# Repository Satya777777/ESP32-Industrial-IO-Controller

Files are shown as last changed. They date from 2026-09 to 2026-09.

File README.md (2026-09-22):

# ESP32 Industrial I/O Controller

A custom 4-layer ESP32-based industrial I/O controller designed in KiCad.

## Features

- ESP32-WROOM-32E
- 24 V input
- 0–10 V analog input
- 4–20 mA analog input
- RS485 communication
- USB-C programming/debugging
- 24 V relay output
- 5 V buck converter
- 3.3 V regulation
- 4-layer PCB
- Dedicated GND plane

## System Architecture

Architecture

## PCB

3D PCB

## Documentation

- [Datasheet & User Manual](docs/ESP32_Industrial_IO_Controller_Datasheet_User_Manual.pdf)
- [Design Process & Engineering Record](docs/ESP32_Industrial_IO_Controller_Design_Process.pdf)

## Hardware

- KiCad schematic
- KiCad PCB
- Gerber files
- Drill files

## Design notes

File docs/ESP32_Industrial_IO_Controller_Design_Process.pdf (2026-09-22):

ESP32 Industrial I/O Controller — Design Process
ENGINEERING DOCUMENT

# ESP32 Industrial I/O Controller

# Complete PCB Design Process & Engineering Record

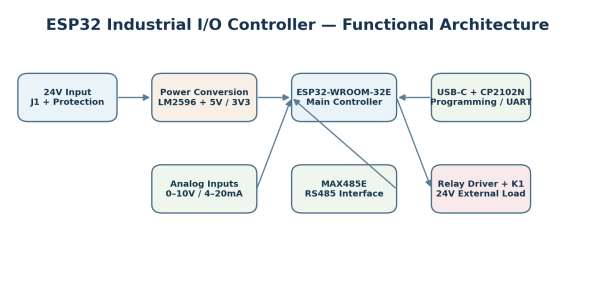
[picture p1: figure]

Document ID | EIC-4L-ENG-001
Documentation Revision | 1.0
Design Revision | Rev A — Routed PCB
Toolchain | KiCad PCB + Schematic Editors
Board | 4-layer FR-4, nominal 1.6 mm
Prepared for | Portfolio / GitHub / LinkedIn engineering record

Documentation note: This document records the design decisions and implementation state captured during the KiCad PCB development workflow. Values or performance limits not explicitly established in the project record are marked as design targets or items to verify before production.

# Contents

1. Project Definition
2. Requirements
3. Architecture and Partitioning
4. Component Selection
5. PCB Stackup and Design Rules
6. Schematic Development
7. Footprint and Mechanical Decisions
8. PCB Placement Evolution
9. Routing Strategy and Execution
10. Verification and DRC
11. Final Gerber Inspection
12. Key Design Decisions and Change Log
13. Final Engineering Status
14. Portfolio Documentation Notes

# 1. Project Definition

Goal. Design a compact industrial-style ESP32 controller PCB that combines 24V field power, protected 5V/3.3V rails, USB service access, RS485, analog process inputs, and a relay-controlled external load interface in one 4-layer board.

- Controller core: ESP32-WROOM-32E.
- Service interface: USB-C with CP2102N USB-UART bridge.
- Industrial communications: MAX485E RS485 transceiver.
- Analog interfaces: one 0–10V input and one 4–20mA input.
- Field power: nominal 24V input with protection and fused board power.
- Outputs: 24V relay interface; external load target up to 5A inductive through relay contacts.
- PCB approach: 4 layers, solid inner GND plane, edge-accessible field connectors.

# 2. Requirements

Category | Requirement / target | Implementation
Power | 24V field input | J1 → F1 → Q3 protection → 24V_PROTECTED
Power | 5V rail | LM2596S-5 buck stage
Power | 3.3V rail | TLV76733 linear regulator
USB | USB service/programming | USB-C + CP2102N
Analog | 0–10V sensor | Protected divider/filter to GPIO34
Analog | 4–20mA sensor | 150 Ω shunt + filter/protection to GPIO35
Comms | RS485 | MAX485E + A/B terminal
Output | Relay output | JQC-3FF-024-1Z SPDT relay
Load | External motor/load target | Up to 5A inductive at the external relay-contact path; verify final thermal/current margin before production
PCB | 4-layer, 1.6 mm nominal | F.Cu / In1.Cu / In2.Cu / B.Cu

# 3. Architecture and Partitioning

Figure 1. Functional architecture used to partition the PCB into power, digital, analog, communications, and relay zones.

- Power section kept in the lower portion of the board to isolate switching currents from analog and RF-sensitive circuitry.
- ESP32 placed near the upper center with its antenna facing the board edge and a dedicated keep-out region.
- Analog connectors placed at the left edge, with conditioning components immediately inboard.
- RS485 connector and MAX485E placed together at the right edge.
- Relay and external-load connector placed together in the lower-right zone.
- USB-C and CP2102N grouped at the upper-left service area.

# 4. Component Selection

Core components and selected packages. The selection was made around the required electrical function, field accessibility, and KiCad footprint/3D-model availability.

Function | Part / value | PCB package / footprint decision
MCU | ESP32-WROOM-32E | RF_Module:ESP32-WROOM-32D style WROOM footprint used in the project
USB-UART | CP2102N | QFN-24 footprint with exposed GND pad
RS485 | MAX485E | SOIC-8 footprint
5V buck | LM2596S-5 | Power IC with external diode / inductor / capacitors
3.3V LDO | TLV76733DRVx | SOT-23-6 family footprint used for the project symbol/PCB mapping
Relay | JQC-3FF-024-1Z | Relay_THT:Relay_SPDT_Hongfa_JQC-3FF_0XX-1Z
24V field terminals | Phoenix Contact MKDS family | 2-position 5.08 mm Phoenix footprint
3-way relay terminal | Phoenix Contact MKDS family | 3-position 5.08 mm Phoenix footprint

Function | Part / value | PCB package / footprint decision
Resistors | 10k, 20k, 47.5k, 150 Ω etc. | 0805 metric for SMD resistors
Caps | 0.1 µF to 22 µF SMD | 0603/0805/1206 selected by value/function
Bulk caps | 680 µF / 220 µF | Through-hole radial footprints

# 5. PCB Stackup and Design Rules

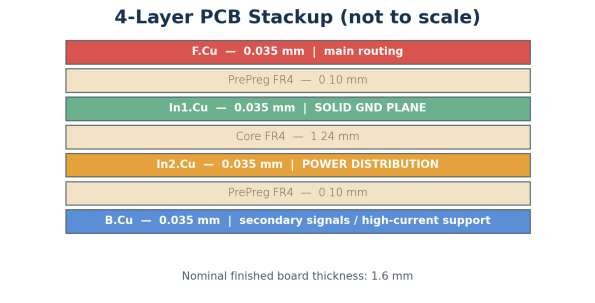
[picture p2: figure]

Figure 2. Final 4-layer conceptual stackup and assigned layer functions.

Layer / rule | Final project setting | Purpose
F.Cu | Signal / component side | Main routing and local power
In1.Cu | Solid GND plane | Continuous low-impedance return plane
In2.Cu | Power + selected routes | 24V, 5V, 3V3 distribution
B.Cu | Signals + high-current support | Secondary routing and additional copper
Minimum clearance | 0.20 mm | Primary spacing constraint
Minimum track width | 0.20 mm | Board-level minimum
Minimum connection width | 0.20 mm | DRC connection rule
Minimum via diameter | 0.60 mm | Standard via preset
Through-hole minimum | 0.20 mm after DRC adjustment | Accommodates small footprint holes; verify fab capability

Grounding decision. The final plan uses a continuous In1.Cu GND plane rather than an arbitrary split/star architecture. Local return paths remain short and return-current-aware.

# 6. Schematic Development

1. Functional blocks were drawn first: MCU, power tree, USB-UART, RS485, analog inputs, relay driver, and field connectors.
2. Nets were named to make PCB routing explicit: +3V3, +5V, VBUS, SYS_5V, 24V_PROTECTED, ANALOG_0_10V, ANALOG_4_20mA, RS485_A, RS485_B and control nets.
3. ERC cleanup included annotation/grid correction; the project reached zero schematic errors in the development workflow.
4. Footprints were then assigned to all components, with special attention to manufacturer-specific connector geometry and 3D models.
5. The schematic was used as the source of connectivity while PCB Editor handled physical placement and routing.
Block | Key implementation details
ESP32 | EN/reset network, BOOT switch, RESET switch, local decoupling
3.3V | TLV76733 with input/output capacitors
USB | USB-C → CP2102N; USB support passives grouped locally
24V protection | J1 → F1 → PMOS Q3 + protection parts → 24V_PROTECTED
Buck | LM2596S-5 + 680 µF input + Schottky diode + 33 µH + 220 µF output
Analog 0–10V | Protection/clamp + divider + 100 nF filtering to GPIO34
Analog 4–20mA | 5V clamp + 150 Ω shunt + 100 nF filtering to GPIO35
RS485 | MAX485E + bias resistors + 120 Ω termination
Relay | 24V coil + Q4 BSS138 low-side drive + D5 flyback + J3 SPDT output

# 7. Footprint and Mechanical Decisions

- Generic 2-pin screw terminal footprints were replaced with manufacturer-specific Phoenix Contact MKDS family footprints to obtain a realistic mechanical envelope and usable 3D model.
- The same approach was applied to the 3-pin relay output terminal.
- Connector bodies were kept on board edges so field wiring can be inserted from outside the PCB without mechanical obstruction.
- The ESP32 antenna keep-out was preserved during every placement iteration.
- A nominal 1.6 mm board thickness was retained as the manufacturing/mechanical baseline.

Important production note. The Phoenix footprint selection records the PCB geometry, but the actual purchased part must still match the selected MPN and pitch during BOM procurement.

# 8. PCB Placement Evolution

Area | Initial condition | Final decision / change
USB | CP2102N was initially too far from USB-C | Moved U2 close to J2 and kept USB passives local
ESP32/RF | MCU centered with large antenna region | Kept at top/center with antenna at edge and keep-out preserved

Area | Initial condition | Final decision / change
Analog | Conditioning existed but had extra spacing | Grouped immediately behind J5/J6
RS485 | U3 and connector separated during early placement | Grouped U3 + J4 + termination/bias parts
Buck | Components appeared visually spread in 2D | 3D inspection showed acceptable physical proximity; no unnecessary compression
3.3V | U4/C1/C2 were reviewed for proximity | C1/C2 retained close to regulator
24V input | J1, F1 and protection parts at lower-left | Kept as a compact power-entry block
Relay | Relay and output connector at lower-right | Kept K1 + Q4 + D5 + driver passives + J3 together
Board outline | Started near 100 × 70 mm | Reduced after placement to remove large unused perimeter area
- Placement was deliberately refined using both 2D PCB Editor and 3D Viewer rather than optimizing only for visual compactness.
- After the design was compact enough, the central open area was retained as routing and isolation space instead of forcing the outline smaller.

# 9. Routing Strategy and Execution

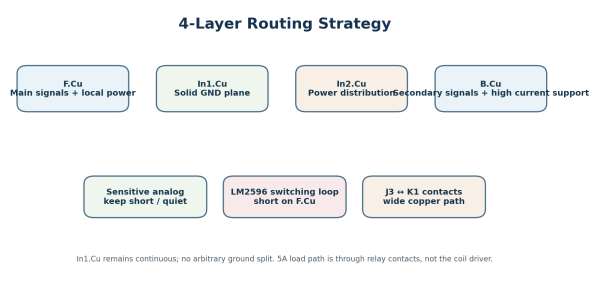
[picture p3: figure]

Figure 3. Layer-aware routing strategy used during execution.

1. LM2596 switching loop first, keeping the high-frequency loop compact on F.Cu and avoiding unnecessary vias.
2. 24V entry and protected power distribution next.
3. External motor/load path through the relay contacts using wide copper; the 5A load path is not routed through the relay coil driver.
4. 5V and 3.3V rail distribution, with local regulator capacitor connections kept short.
5. USB D+ / D− kept together and short between J2 and CP2102N.
6. RS485 A/B routed as a short coupled pair near U3/J4, with the 120 Ω termination kept close to the interface.
7. Analog channels routed short and away from switching/high-current regions.

8. Relay control wiring routed locally around Q4/D5/R11/R12.
9. Remaining ESP32 signals routed last, using B.Cu only when it improved routability.
Layer | Routing policy
F.Cu | Main signals, local power, LM2596 critical loop, analog, USB, RS485
In1.Cu | GND plane; no arbitrary split
In2.Cu | Main power distribution
B.Cu | Secondary signals and support for high-current copper

# 10. Verification and DRC

Check | Observed result / decision
PCB DRC violations | 0 after the final check
Unconnected items | 0
Schematic parity | An outstanding U4/footprint parity exception was ignored in the working release after PCB connectivity had already been verified; fix before a strict source-controlled release
Minimum drill | Rule adjusted to 0.20 mm to accommodate small footprint holes; confirm fab drill capability
Ground plane | In1.Cu verified as continuous GND plane in Gerber Viewer
Power layer | In2.Cu inspected for routed power copper
Gerbers | Opened in Gerber Viewer and reviewed layer-by-layer

Release discipline. A portfolio-ready record can show zero DRC and zero unconnected items while still disclosing source-parity exceptions. For production release, the schematic/PCB pair should be synchronized so the parity check also passes without exclusions.

# 11. Final Gerber Inspection

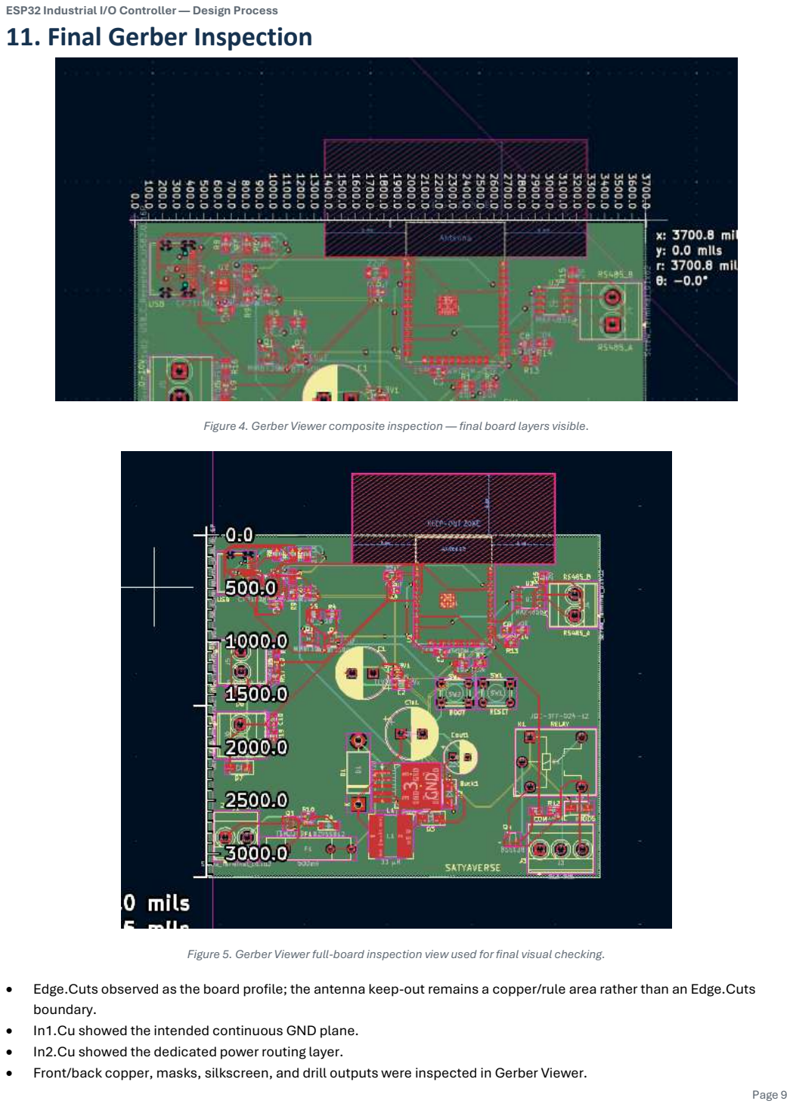
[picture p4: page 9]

Figure 4. Gerber Viewer composite inspection — final board layers visible.

Figure 5. Gerber Viewer full-board inspection view used for final visual checking.

- Edge.Cuts observed as the board profile; the antenna keep-out remains a copper/rule area rather than an Edge.Cuts boundary.
- In1.Cu showed the intended continuous GND plane.
- In2.Cu showed the dedicated power routing layer.
- Front/back copper, masks, silkscreen, and drill outputs were inspected in Gerber Viewer.

# 12. Key Design Decisions and Change Log

Decision | Earlier approach | Final approach | Reason
Layer count | 3-layer / 4-layer considered | 4-layer | Dedicated GND plane + separate power layer
Connector footprint | Generic terminal block | Phoenix MKDS family | Mechanical realism + 3D model + field accessibility
Grounding | Split/star concepts considered during review | Continuous In1.Cu GND plane | Predictable return paths and easier controlled routing
USB placement | U2 had extra distance from J2 | U2 close to J2 | Shorter USB differential routing
Buck placement | 2D view looked spread | Kept physically compact; no further forced compression | 3D view confirmed adequate proximity
Board size | Initial ~100 × 70 mm | Reduced outline | Remove unnecessary perimeter only after placement stabilized
U4 capacitor placement | Reviewed repeatedly | C1/C2 kept at practical proximity | Avoid unnecessary movement once physically correct
DRC hole rule | 0.30 mm min drill | 0.20 mm min drill | Accommodate footprint hole geometry; fab capability to be verified
User silkscreen | Minimal references | Added field labels | Make the board usable without schematic lookup

# 13. Final Engineering Status

Stage | Status
Requirements | Complete
Architecture | Complete
Component selection | Complete with recorded footprint changes
Schematic | Complete for working PCB revision
Footprints | Assigned
Placement | Complete
Routing | Complete
Ground plane | Complete
DRC / unconnected | 0 / 0
Gerber review | Complete
User silkscreen | Complete

Before fabrication. Verify final manufacturer stackup, copper thickness, controlled-drill capability, relay/terminal current ratings, thermal margin for the 5A external load target, enclosure mechanics, and BOM/MPN consistency.

# 14. Portfolio Documentation Notes

- Recommended GitHub repository folders: /docs, /kicad, /gerbers, /images, /bom.
- Put this engineering record in /docs as the project history and decision log.
- Use the companion datasheet/user manual as the external-facing document for someone who wants to understand or operate the board.
- Keep the final KiCad project, schematic, PCB, fabrication output, and BOM under revision control together.

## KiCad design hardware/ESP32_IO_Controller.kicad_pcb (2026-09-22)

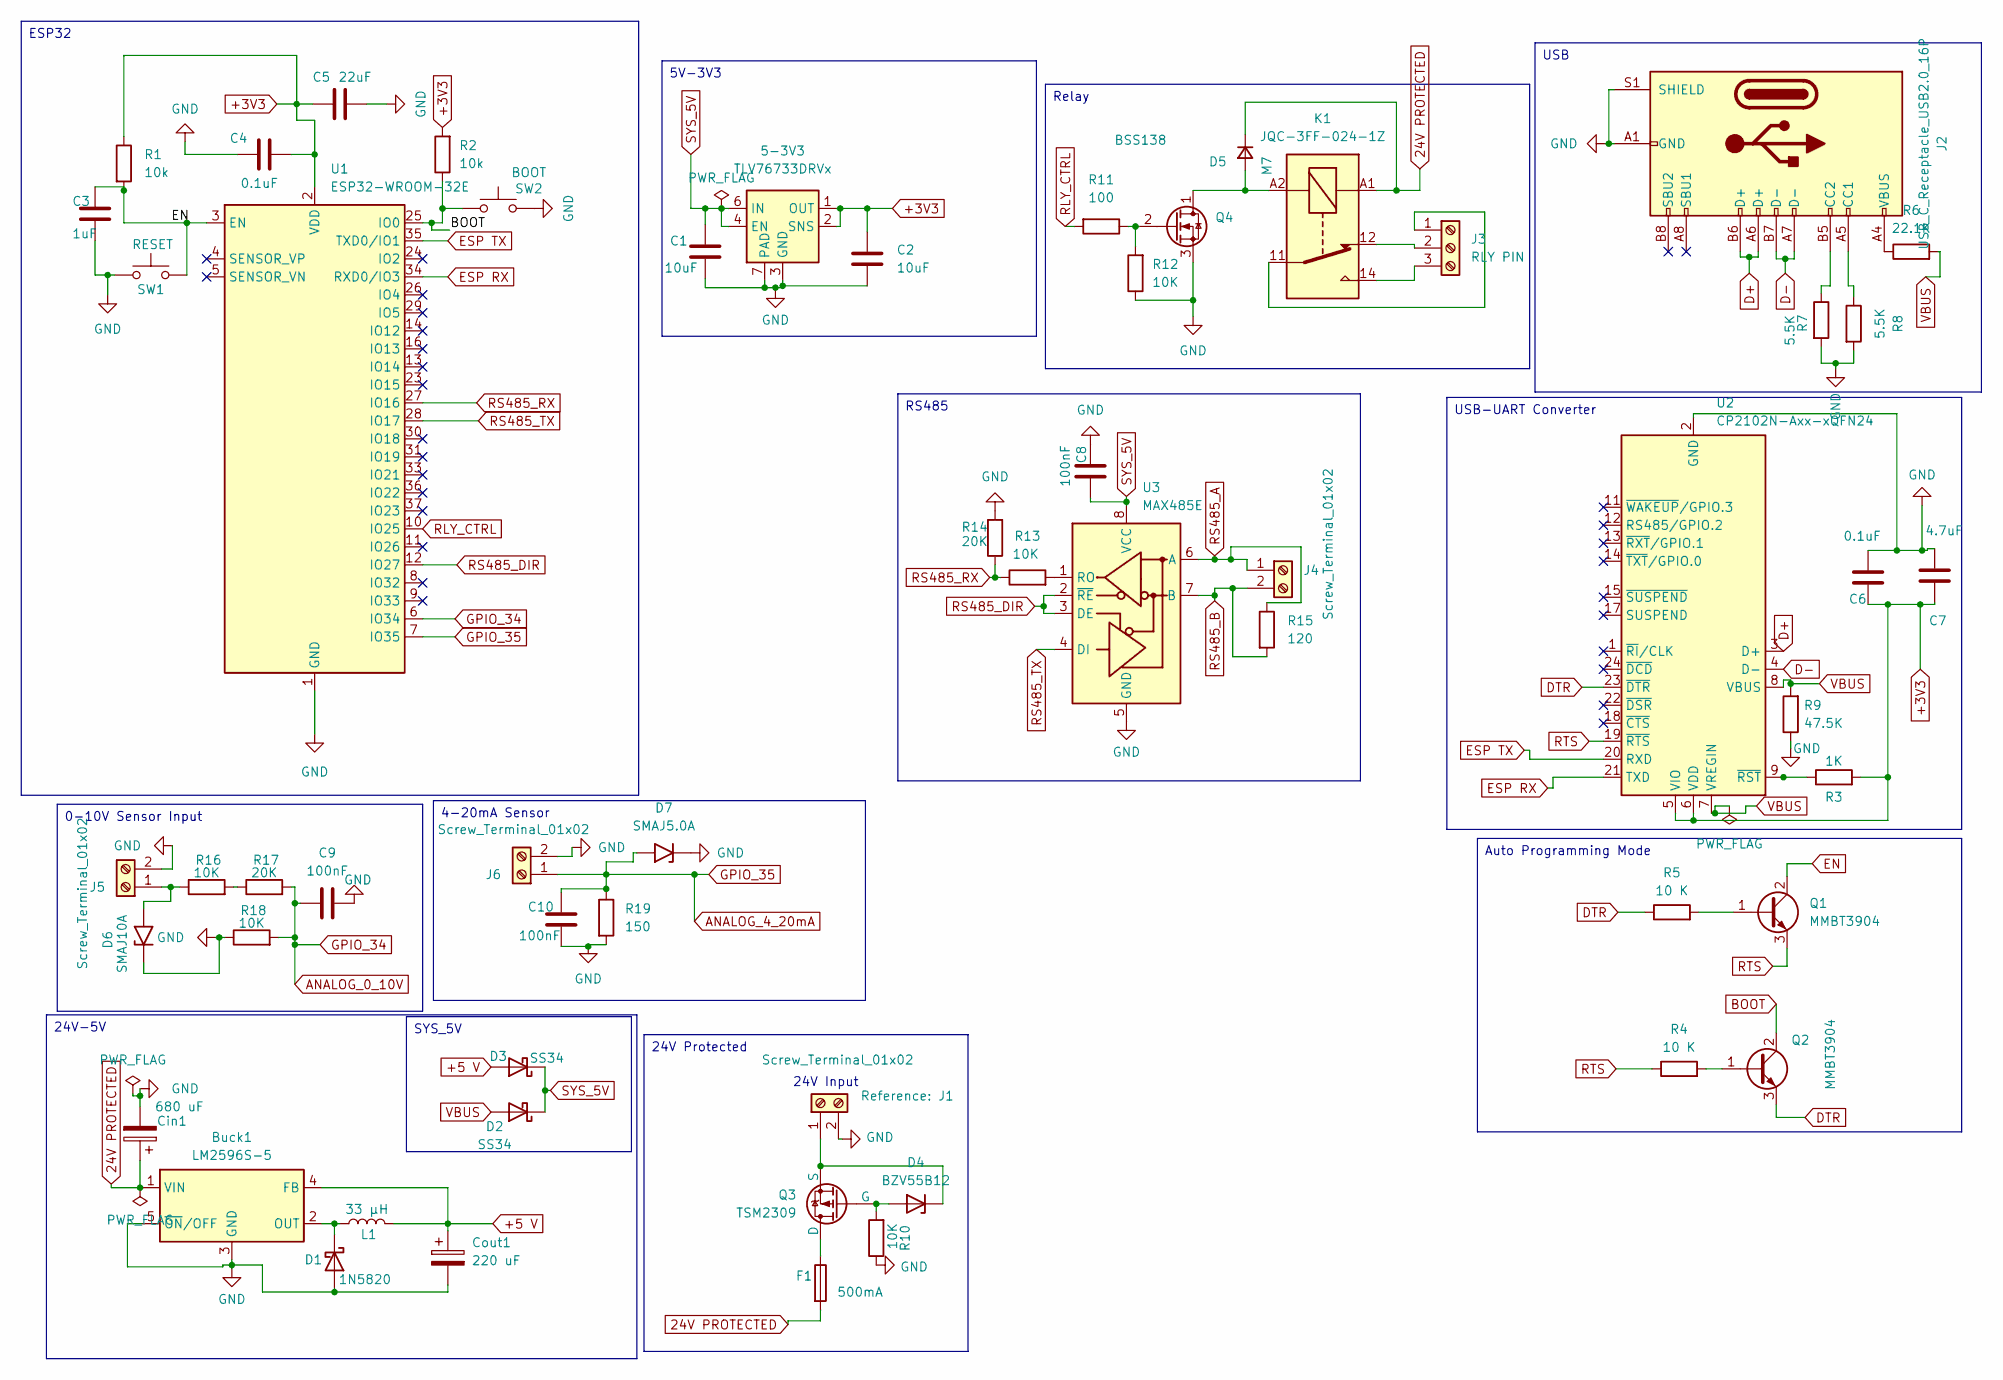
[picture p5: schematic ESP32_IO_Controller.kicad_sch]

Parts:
5-3V3: TLV76733DRVx; WSON-6-1EP_2x2mm_P0.65mm_EP1x1.6mm_ThermalVias
Buck1: LM2596S-5; TO-263-5_TabPin3
C1: 10uF; CP_Radial_D12.5mm_P5.00mm
C2: 10uF; C_1206_3216Metric
C3: 1uF; C_0805_2012Metric
C4, C6: 0.1uF; C_0603_1608Metric
C5: 22uF; C_1206_3216Metric
C7: 4.7uF; C_0805_2012Metric
C8, C9: 100nF; C_0603_1608Metric
C10: 100nF; C_0805_2012Metric
Cin1: 680 uF; CP_Radial_D12.5mm_P5.00mm
Cout1: 220 uF; CP_Radial_D8.0mm_P3.50mm
D1: 1N5820; D_DO-201AD_P15.24mm_Horizontal
D2, D3: SS34; D_SMA
D4: BZV55B12; D_MiniMELF
D5: M7; D_SMA
D6: SMAJ10A; D_SMA
D7: SMAJ5.0A; D_SMA
F1: 500mA; Fuseholder_Clip-5x20mm_Schurter_CQM_Inline_P20.60x5.00mm_D1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
J1, J4, J5, J6: Screw_Terminal_01x02; TerminalBlock_Phoenix_MKDS-3-2-5.08_1x02_P5.08mm_Horizontal
J2: USB_C_Receptacle_USB2.0_16P; USB_C_Receptacle_HRO_TYPE-C-31-M-12
J3: RLY PIN; TerminalBlock_Phoenix_MKDS-3-3-5.08_1x03_P5.08mm_Horizontal
K1: JQC-3FF-024-1Z; Relay_SPDT_Hongfa_JQC-3FF_0XX-1Z
L1: 33 µH; L_Bourns-SRN1060
Q1, Q2: MMBT3904; SOT-23
Q3: TSM2309; SOT-23
Q4: BSS138; SOT-23
R1, R2: 10k; R_0805_2012Metric
R3: 1K; R_0805_2012Metric
R4, R5: 10 K; R_0805_2012Metric
R6: 22.1K; R_0805_2012Metric
R7, R8: 5.5K; R_0805_2012Metric
R9: 47.5K; R_0805_2012Metric
R10, R12, R13, R16, R18: 10K; R_0805_2012Metric
R11: 100; R_0805_2012Metric
R14, R17: 20K; R_0805_2012Metric
R15: 120; R_0805_2012Metric
R19: 150; R_0805_2012Metric
SW1: RESET; SW_PUSH_6mm
SW2: BOOT; SW_PUSH_6mm
U1: ESP32-WROOM-32E; ESP32-WROOM-32D
U2: CP2102N-Axx-xQFN24; QFN-24-1EP_4x4mm_P0.5mm_EP2.6x2.6mm
U3: MAX485E; SOIC-8_3.9x4.9mm_P1.27mm

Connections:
24V PROTECTED: Buck1.1 (VIN), Cin1.1, D5.1 (K), F1.2, K1.A1
+3V3: 5-3V3.1 (OUT), 5-3V3.2 (SNS), C2.1, C4.2, C5.1, C6.1, C7.1, R1.1, R2.2, R3.2, U1.2 (VDD), U2.5 (VIO), U2.6 (VDD); also elsewhere on the board
+5 V: Buck1.4 (FB), Cout1.1, D3.2 (A), L1.2
ANALOG_0_10V: C9.1, R17.2, R18.2, U1.6 (IO34)
ANALOG_4_20mA: C10.1, D7.2 (A2), J6.1 (4-20mA), R19.1, U1.7 (IO35)
BOOT: Q2.2 (C), R2.1, SW2.1, U1.25 (IO0)
D+: J2.A6 (D+), J2.B6 (D+), U2.3 (D+)
D-: J2.A7 (D-), J2.B7 (D-), U2.4 (D-)
DTR: Q2.3 (E), R5.1, U2.23 (~DTR)
EN: C3.2, Q1.2 (C), R1.2, SW1.2, U1.3 (EN)
ESP RX: U1.34 (RXD0/IO3), U2.21 (TXD)
ESP TX: U1.35 (TXD0/IO1), U2.20 (RXD)
GND: 5-3V3.3 (GND), 5-3V3.5 (GND), 5-3V3.7 (PAD), Buck1.3 (GND), Buck1.5 (~ON/OFF), C1.2, C2.2, C3.1, C4.1, C5.2, C6.2, C7.2, C8.1, C9.2, C10.2, Cin1.2, Cout1.2, D1.2 (A), D6.1 (A1), D7.1 (A1), J1.2 (GND), J2.A1 (GND), J2.A12 (GND), J2.B1 (GND), J2.B12 (GND), J2.S1 (SHIELD), J5.2 (GND), J6.2 (GND), Q4.3 (S), R7.2, R8.2, R9.1, R10.1, R12.1, R14.2, R18.1, R19.2, SW1.1, SW2.2, U1.1 (GND), U1.15 (GND), U1.38 (GND), U1.39 (GND), U2.2 (GND), U2.25 (GND), U3.5 (GND); also elsewhere on the board
unnamed: Buck1.2 (OUT), D1.1 (K), L1.1
unnamed: D4.2 (A), Q3.2 (G), R10.2
unnamed: D4.1 (K), J1.1 (24V), Q3.3 (S)
unnamed: D5.2 (A), K1.A2, Q4.1 (D)
unnamed: D6.2 (A2), J5.1 (0-10_V), R16.1
unnamed: J2.A5 (CC1), R8.1
unnamed: J2.B5 (CC2), R7.1
unnamed: J2.A4 (VBUS), J2.A9 (VBUS), J2.B4 (VBUS), J2.B9 (VBUS), R6.1
unnamed: J3.1 (COM), K1.11
unnamed: J3.2 (NC), K1.12
unnamed: J3.3 (NO), K1.14
unnamed: Q1.1 (B), R5.2
unnamed: Q2.1 (B), R4.2
unnamed: F1.1, Q3.1 (D)
unnamed: Q4.2 (G), R11.1, R12.2
unnamed: R16.2, R17.1
unnamed: R3.1, U2.9 (~RST)
unnamed: R13.2, U3.1 (RO)
RLY_CTRL: R11.2, U1.10 (IO25)
RS485_A: J4.1 (A), R15.1, U3.6 (A)
RS485_B: J4.2 (B), R15.2, U3.7 (B)
RS485_DIR: U1.12 (IO27), U3.2 (~RE), U3.3 (DE)
RS485_RX: R13.1, R14.1, U1.27 (IO16)
RS485_TX: U1.28 (IO17), U3.4 (DI)
RTS: Q1.3 (E), R4.1, U2.19 (~RTS)
SYS_5V: 5-3V3.4 (EN), 5-3V3.6 (IN), C1.1, C8.2, D2.1 (K), D3.1 (K), U3.8 (VCC); also elsewhere on the board
VBUS: D2.2 (A), R6.2, R9.2, U2.7 (VREGIN), U2.8 (VBUS)

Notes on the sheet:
24V Input
USB-UART Converter
0-10V Sensor Input
Auto Programming Mode
24V-5V
4-20mA Sensor
ESP32
SYS_5V
Relay
USB
24V Protected
RS485
5V-3V3

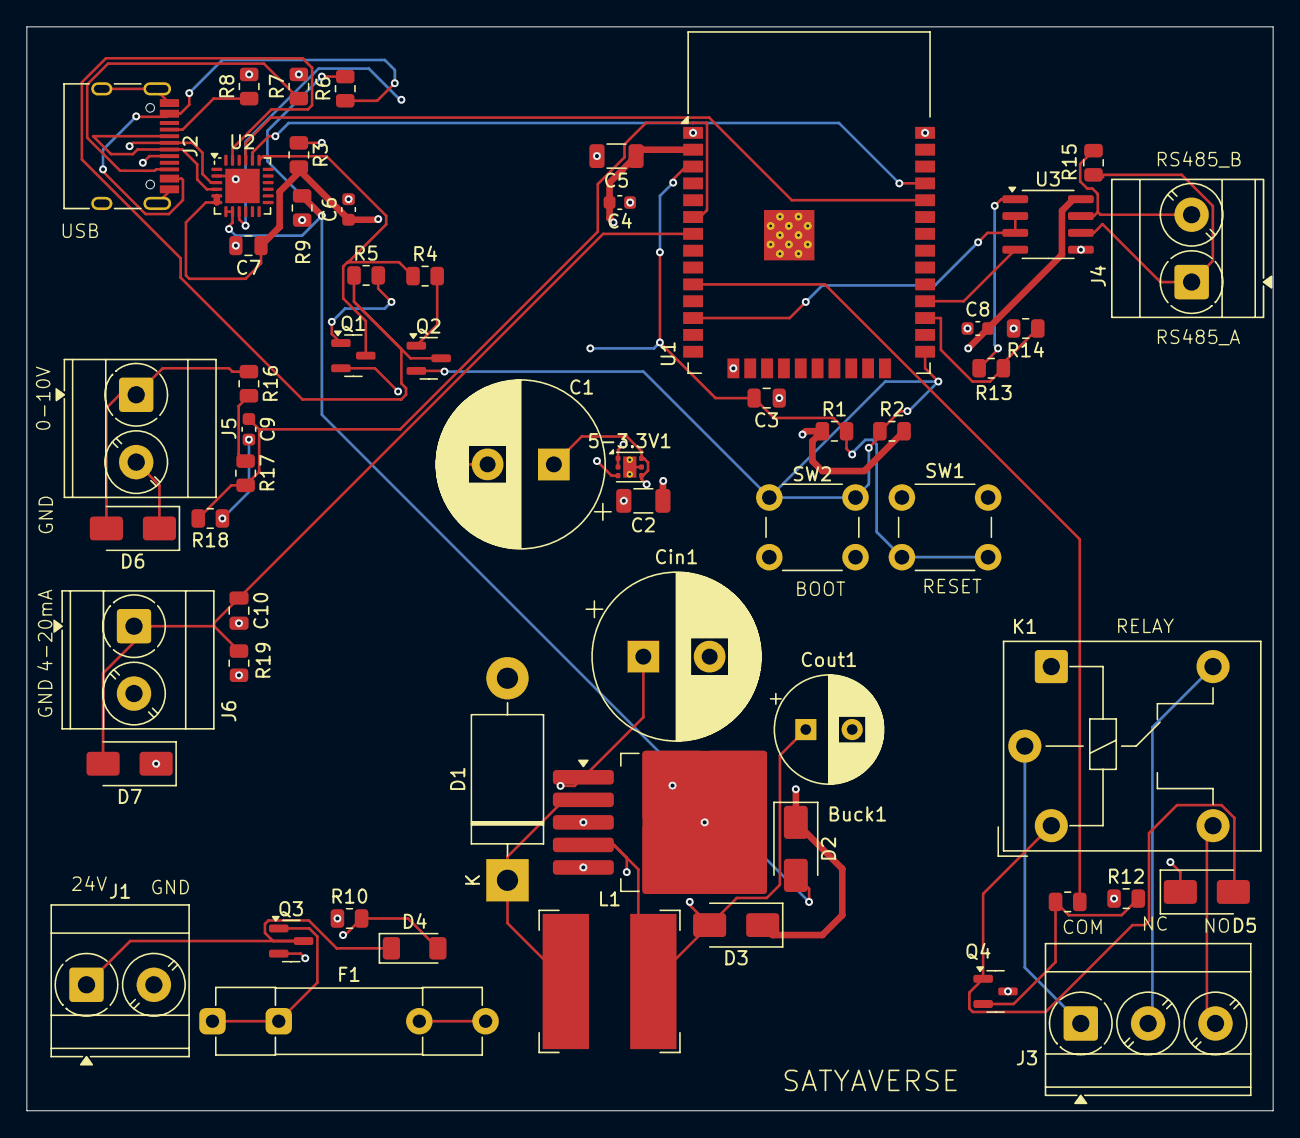
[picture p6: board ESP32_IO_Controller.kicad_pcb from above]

Board: 4 copper layers, 94.0 x 81.8 mm, 58 parts (0 on the bottom side), 40 nets.

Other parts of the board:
5-3.3V1: TLV76733DRVx; WSON-6-1EP_2x2mm_P0.65mm_EP1x1.6mm_ThermalVias

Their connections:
+3V3: 5-3.3V1.1 (OUT), 5-3.3V1.2 (SNS); also elsewhere on the board
GND: 5-3.3V1.3 (GND), 5-3.3V1.5 (GND), 5-3.3V1.7 (PAD); also elsewhere on the board
SYS_5V: 5-3.3V1.4 (EN), 5-3.3V1.6 (IN); also elsewhere on the board
